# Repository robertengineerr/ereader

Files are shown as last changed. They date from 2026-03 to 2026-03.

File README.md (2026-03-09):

# e-reader

An open-source e-reader built on the ESP32-S3. Bare-metal C++ firmware, web-based book management, physical controls. Designed for FOSS developers to build on top of solid hardware.

## Schematic



The full KiCad project is in [`hardware/e_reader_v0.1/`](hardware/e_reader_v0.1/). Pin reference is in [`hardware/connections.md`](hardware/connections.md).

## Hardware

| Component | Part |
|---|---|
| MCU | ESP32-S3-DevKitC-1 (N16R8, 16MB flash, 8MB PSRAM) |
| Display | Waveshare 7.5" V2 e-ink (800×480) |
| Storage | MicroSD socket, SPI, FAT32 |
| Input | 7× tactile buttons |
| Battery | 3.7V LiPo via JST-PH, MCP73831 charger |
| Power | USB-C (charging + programming), AP2112 3.3V LDO |

### Wiring

**Display (FSPI / SPI2)**
| Signal | GPIO | Notes |
|---|---|---|
| PWR | 3 | Drive HIGH to power display |
| CS | 10 | |
| CLK | 9 | |
| DIN (MOSI) | 46 | |
| DC | 11 | |
| RST | 12 | |
| BUSY | 13 | |

**SD Card (HSPI / SPI3)**
| Signal | GPIO |
|---|---|
| CS | 15 |
| MOSI | 16 |
| SCK | 17 |
| MISO | 18 |

> Use a 3.3V-native SD socket (no onboard LDO). DAT1 and DAT2 must be pulled to 3.3V via 10k resistors.

**Buttons**
| Button | GPIO | Notes |
|---|---|---|
| UP | 36 | INPUT_PULLUP, FALLING interrupt |
| DOWN | 37 | INPUT_PULLUP, FALLING interrupt |
| LEFT | 38 | INPUT_PULLUP, FALLING interrupt |
| RIGHT | 39 | INPUT_PULLUP, FALLING interrupt |
| MID | 40 | INPUT_PULLUP, FALLING interrupt |
| SET | 41 | Hold at boot → WiFi mode |
| RST | 42 | Reserved |

## Building

1. Install [PlatformIO](https://platformio.org/)
2. Create `src/secrets.h` with your WiFi credentials:
```cpp
#define WIFI_SSID "your-ssid"
#define WIFI_PASS "your-password"
```
3. Build and flash:
```bash
pio run --target upload
```

## Usage

| Button | Library | Reading | Settings |
|---|---|---|---|
| UP | Cursor up | Previous page | Cursor up |
| DOWN | Cursor down | Next page | Cursor down |
| RIGHT | — | Next page | — |
| MID | Select | Back to library | Select |
| LEFT | — | Back to library | Back to library |
| Hold SET at boot | — | — | Enter WiFi mode |

### WiFi Upload

Hold SET while pressing reset, or navigate **Settings → WiFi Upload**. The device connects to your WiFi and shows `ereader.local` on screen. Open `http://ereader.local` in a browser to upload and delete books.

Supported formats (converted to plain text in the browser):
- `.txt` — uploaded directly
- `.epub` — extracted in browser via JSZip
- `.pdf` — extracted via PDF.js
- `.docx` — extracted via JSZip
- `.html` / `.htm` — stripped in browser
- `.fb2` — parsed in browser

Press MID on the device or click **Exit WiFi Mode** in the browser to return to the library.

### Fallback

If no SD card is present the device falls back to a built-in sample text (Iliad Book I, Pope translation) so the UI is always usable.

## Project Structure

```
src/
  main.cpp          # setup, loop, ISR input handling, state machine
  display.cpp/h     # e-ink display abstraction (GxEPD2)
  sd_manager.cpp/h  # SD card init, book listing, pagination engine
  network.cpp/h     # WiFi, HTTP file manager, mDNS
  web_ui.h          # embedded HTML/JS for the browser file manager
  secrets.h         # WiFi credentials (not in repo — create your own)

hardware/
  connections.md              # full pin reference for KiCad
  e_reader_v0.1/              # KiCad project (schematic + PCB)
```

## Roadmap

- [x] Text rendering on e-ink display
- [x] SD card file management
- [x] State machine UI (Library / Reading / Settings)
- [x] WiFi upload with multi-format support
- [x] mDNS (`ereader.local`)
- [x] Hardware schematic v0.1
- [ ] PCB layout and fabrication (JLCPCB)
- [ ] LiPo battery + charging circuit (MCP73831 + AP2112)
- [ ] Persist reading position (LittleFS)
- [ ] EPUB native rendering
- [ ] 3D printed enclosure

## License

MIT

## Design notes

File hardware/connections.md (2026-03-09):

# E-Reader v0.1 — Pin Connections Reference

KiCad project path: `/Users/robbiethomas/Documents/PlatformIO/Projects/e_reader_v0.1/hardware/`

MCU: **ESP32-S3-DevKitC-1 (N16R8)**

---

## E-Paper Display — Waveshare 7.5" V2 (800×480)
Interface: **FSPI (SPI2)**
Portrait orientation: 480px wide × 800px tall (setRotation(1))

| Display Pin | ESP32-S3 GPIO | Notes |
|---|---|---|
| PWR | GPIO3 | OUTPUT HIGH to power on |
| BUSY | GPIO13 | Input, active HIGH while refreshing |
| RST | GPIO12 | Active LOW reset |
| DC | GPIO11 | Data/Command select |
| CS | GPIO10 | SPI chip select, active LOW |
| CLK | GPIO9 | FSPI clock |
| DIN (MOSI)  | GPIO46 | FSPI MOSI |
| VCC | 3.3V | |
| GND | GND | |

SPI settings: 4 MHz, MSBFIRST, SPI_MODE0

---

## SD Card Module — UMLIFE 3.3V (or equivalent)
Interface: **HSPI (SPI3)**

| SD Pin | ESP32-S3 GPIO | Notes |
|---|---|---|
| CS | GPIO15 | SPI chip select, active LOW |
| MOSI | GPIO16 | HSPI MOSI |
| SCK | GPIO17 | HSPI clock |
| MISO | GPIO18 | HSPI MISO |
| VCC | 3.3V | Must be 3.3V-native module (no onboard LDO) |
| GND | GND | |

SPI speed: 4 MHz. FAT32 formatted, .txt files in root.

---

## 5-Way Joystick
COM pin is driven LOW by GPIO (virtual GND). All direction pins are INPUT_PULLUP — pressed = LOW (FALLING edge interrupt).

| Joystick Pin | ESP32-S3 GPIO | Mode | Function |
|---|---|---|---|
| COM | GPIO35 | OUTPUT LOW | Virtual GND for joystick |
| UP | GPIO36 | INPUT_PULLUP + INT | Navigate up / previous page |
| DOWN | GPIO37 | INPUT_PULLUP + INT | Navigate down / next page |
| LEFT | GPIO38 | INPUT_PULLUP + INT | Back to library |
| RIGHT | GPIO39 | INPUT_PULLUP + INT | Next page (reading mode) |
| MID (press)  | GPIO40 | INPUT_PULLUP + INT | Select / back to library / exit WiFi |
| SET | GPIO41 | INPUT_PULLUP | Hold at boot → enter WiFi upload mode |
| RST | GPIO42 | INPUT_PULLUP | Reserved (reset / future use) |

All interrupts: FALLING edge, ISR-side debounce at 200 ms.

---

## Power Rails
| Rail  | Source | Consumers |
|---|---|---|
| 3.3V  | DevKitC onboard reg / LiPo + regulator (future) | Display VCC, SD VCC, joystick pull-ups |
| GND | Common ground | All components |

---

## Unused / Reserved GPIOs (available for future use)
GPIO0, GPIO1, GPIO2, GPIO4, GPIO5, GPIO6, GPIO7, GPIO8, GPIO14, GPIO19–GPIO21, GPIO43–GPIO45, GPIO47, GPIO48

---

## WiFi
No external antenna wiring — onboard PCB antenna on DevKitC-1.
SSID / password stored in `src/secrets.h` (not committed to git).
mDNS hostname: `ereader.local`

---

## Notes for Schematic
- Add 100 nF decoupling caps on all VCC pins close to each IC
- Pull-up resistors on BUSY, RST are handled internally by GxEPD2 / MCU
- SD MISO should have a 10k pull-up to 3.3V (some modules include this)
- GPIO35 (JOY_COM) must be rated OUTPUT; on ESP32-S3-DevKitC-1 this is fine
- Future: LiPo charger (TP4056), 3.3V LDO (AP2112K or similar), power switch

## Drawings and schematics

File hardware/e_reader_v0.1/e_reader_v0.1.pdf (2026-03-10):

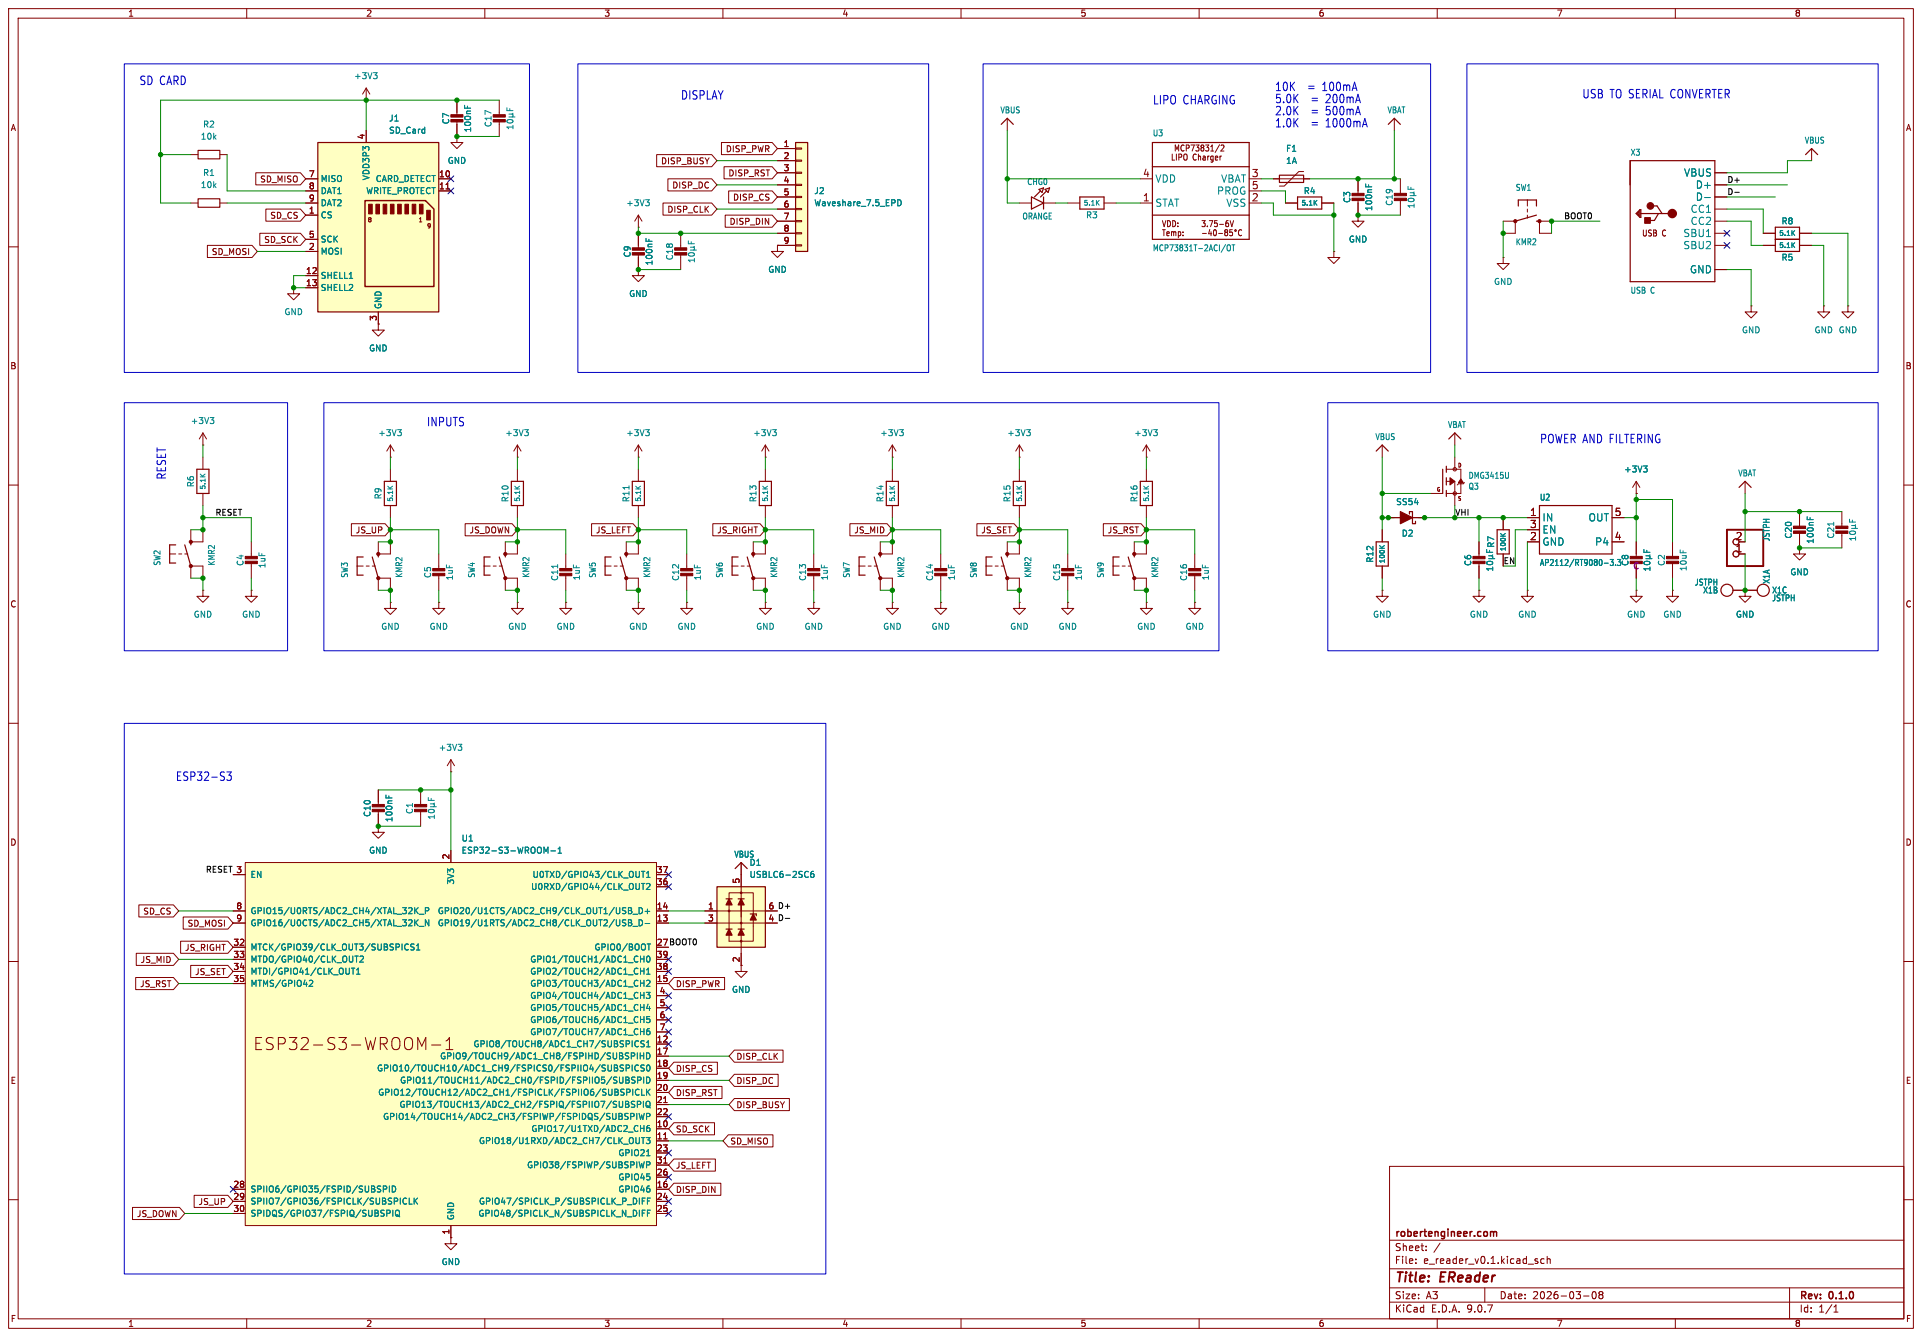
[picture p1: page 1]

USB TO SERIAL CONVERTER

VDD: Temp: LIPO Charger MCP73831/2

1 U0TXD/GPIO43/CLK_OUT1 37 U0RXD/GPIO44/CLK_OUT2 36 GPIO20/U1CTS/ADC2_CH9/CLK_OUT1/USB_D+ 14 GPIO19/U1RTS/ADC2_CH8/CLK_OUT2/USB_D- 13 GPIO0/BOOT 27 GPIO1/TOUCH1/ADC1_CH0 39 GPIO2/TOUCH2/ADC1_CH1 38 GPIO3/TOUCH3/ADC1_CH2 15 GPIO4/TOUCH4/ADC1_CH3 4 GPIO5/TOUCH5/ADC1_CH4 5 GPIO6/TOUCH6/ADC1_CH5 6 GPIO7/TOUCH7/ADC1_CH6 7 GPIO8/TOUCH8/ADC1_CH7/SUBSPICS1 12 GPIO9/TOUCH9/ADC1_CH8/FSPIHD/SUBSPIHD 17 GPIO10/TOUCH10/ADC1_CH9/FSPICS0/FSPIIO4/SUBSPICS0 18 GPIO11/TOUCH11/ADC2_CH0/FSPID/FSPIIO5/SUBSPID 19 GPIO12/TOUCH12/ADC2_CH1/FSPICLK/FSPIIO6/SUBSPICLK 20 GPIO13/TOUCH13/ADC2_CH2/FSPIQ/FSPIIO7/SUBSPIQ 21 GPIO14/TOUCH14/ADC2_CH3/FSPIWP/FSPIDQS/SUBSPIWP 22 GPIO17/U1TXD/ADC2_CH6 10 GPIO18/U1RXD/ADC2_CH7/CLK_OUT3 11 GPIO21 23 GPIO38/FSPIWP/SUBSPIWP 31 GPIO45 26 GPIO46 16 GPIO47/SPICLK_P/SUBSPICLK_P_DIFF 24 GPIO48/SPICLK_N/SUBSPICLK_N_DIFF 25 U1ESP32-S3-WROOM-1 GND C15 1uF

1 U0TXD/GPIO43/CLK_OUT1 37 U0RXD/GPIO44/CLK_OUT2 36 GPIO20/U1CTS/ADC2_CH9/CLK_OUT1/USB_D+ 14 GPIO19/U1RTS/ADC2_CH8/CLK_OUT2/USB_D- 13 GPIO0/BOOT 27 GPIO1/TOUCH1/ADC1_CH0 39 GPIO2/TOUCH2/ADC1_CH1 38 GPIO3/TOUCH3/ADC1_CH2 15 GPIO4/TOUCH4/ADC1_CH3 4 GPIO5/TOUCH5/ADC1_CH4 5 GPIO6/TOUCH6/ADC1_CH5 6 GPIO7/TOUCH7/ADC1_CH6 7 GPIO8/TOUCH8/ADC1_CH7/SUBSPICS1 12 GPIO9/TOUCH9/ADC1_CH8/FSPIHD/SUBSPIHD 17 GPIO10/TOUCH10/ADC1_CH9/FSPICS0/FSPIIO4/SUBSPICS0 18 GPIO11/TOUCH11/ADC2_CH0/FSPID/FSPIIO5/SUBSPID 19 GPIO12/TOUCH12/ADC2_CH1/FSPICLK/FSPIIO6/SUBSPICLK 20 GPIO13/TOUCH13/ADC2_CH2/FSPIQ/FSPIIO7/SUBSPIQ 21 GPIO14/TOUCH14/ADC2_CH3/FSPIWP/FSPIDQS/SUBSPIWP 22 GPIO17/U1TXD/ADC2_CH6 10 GPIO18/U1RXD/ADC2_CH7/CLK_OUT3 11 GPIO21 23 GPIO38/FSPIWP/SUBSPIWP 31 GPIO45 26 GPIO46 16 GPIO47/SPICLK_P/SUBSPICLK_P_DIFF 24 GPIO48/SPICLK_N/SUBSPICLK_N_DIFF 25 GND C10 100nF D1 USBLC6-2SC6

Id: 1/1 Title: EReader File: e_reader_v0.1.kicad_sch Sheet: / robertengineer.com

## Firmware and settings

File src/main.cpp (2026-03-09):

#include <Arduino.h>
#include "display.h"
#include "sd_manager.h"
#include "network.h"

// --- 5-way joystick ---
// COM is wired to a GPIO configured OUTPUT LOW (virtual GND)
#define JOY_COM  35
#define JOY_UP   36
#define JOY_DWN  37
#define JOY_LFT  38
#define JOY_RHT  39
#define JOY_MID  40
#define JOY_SET  41  // hold at boot to enter WiFi upload mode
#define JOY_RST  42

#define DEBOUNCE_MS 200

// Flags set by ISRs; read and cleared in loop()
static volatile bool ev_up    = false;
static volatile bool ev_down  = false;
static volatile bool ev_left  = false;
static volatile bool ev_right = false;
static volatile bool ev_mid   = false;

// Per-button last-fire timestamp for ISR-side debounce
static volatile uint32_t t_up    = 0;
static volatile uint32_t t_down  = 0;
static volatile uint32_t t_left  = 0;
static volatile uint32_t t_right = 0;
static volatile uint32_t t_mid   = 0;

static void IRAM_ATTR isr_up()    { uint32_t n=millis(); if(n-t_up   >DEBOUNCE_MS){ev_up   =true;t_up   =n;} }
static void IRAM_ATTR isr_down()  { uint32_t n=millis(); if(n-t_down >DEBOUNCE_MS){ev_down =true;t_down =n;} }
static void IRAM_ATTR isr_left()  { uint32_t n=millis(); if(n-t_left >DEBOUNCE_MS){ev_left =true;t_left =n;} }
static void IRAM_ATTR isr_right() { uint32_t n=millis(); if(n-t_right>DEBOUNCE_MS){ev_right=true;t_right=n;} }
static void IRAM_ATTR isr_mid()   { uint32_t n=millis(); if(n-t_mid  >DEBOUNCE_MS){ev_mid  =true;t_mid  =n;} }

// --- App state ---
enum AppState { LIBRARY, READING, SETTINGS };

static AppState appState     = LIBRARY;
static int      selectedItem = 0;   // cursor position in LIBRARY or SETTINGS
static int      listScroll   = 0;   // scroll offset for LIBRARY list
static int      currentPage  = 0;

static char bookNames[MAX_BOOKS][MAX_NAME_LEN];
static int  bookCount = 0;

static const char* settingsItems[] = { "WiFi Upload", "Back" };
static const int   SETTINGS_COUNT  = 2;

// ---------------------------------------------------------------------------
// Helpers
// ---------------------------------------------------------------------------

static void clampScroll(int selected, int& scroll, int visible, int total) {
  if (selected < scroll)            scroll = selected;
  if (selected >= scroll + visible) scroll = selected - visible + 1;
}

static void enterLibrary();  // forward declaration

static void returnToLibrary() {
  showPressAnyButton();
  ev_up = ev_down = ev_left = ev_right = ev_mid = false;  // clear stale presses
  while (!ev_up && !ev_down && !ev_left && !ev_right && !ev_mid) delay(10);
  ev_up = ev_down = ev_left = ev_right = ev_mid = false;
  enterLibrary();
}

static void enterLibrary() {
  bookCount = listBooks(bookNames, MAX_BOOKS - 1);
  if (bookCount == 0) {
    strncpy(bookNames[0], "Sample: The Iliad", MAX_NAME_LEN - 1);
    bookNames[0][MAX_NAME_LEN - 1] = '\0';
    bookCount = 1;
  }
  selectedItem = 0;
  listScroll   = 0;
  appState     = LIBRARY;
  showLibraryScreen(bookNames, bookCount, selectedItem, listScroll);
}

// ---------------------------------------------------------------------------
// Setup
// ---------------------------------------------------------------------------

void setup() {
  Serial.begin(115200);

  // Joystick: COM acts as virtual GND so direction pins read LOW when pressed
  pinMode(JOY_COM, OUTPUT);
  digitalWrite(JOY_COM, LOW);
  pinMode(JOY_UP,  INPUT_PULLUP);
  pinMode(JOY_DWN, INPUT_PULLUP);
  pinMode(JOY_LFT, INPUT_PULLUP);
  pinMode(JOY_RHT, INPUT_PULLUP);
  pinMode(JOY_MID, INPUT_PULLUP);
  pinMode(JOY_SET, INPUT_PULLUP);
  pinMode(JOY_RST, INPUT_PULLUP);

  attachInterrupt(JOY_UP,  isr_up,    FALLING);
  attachInterrupt(JOY_DWN, isr_down,  FALLING);
  attachInterrupt(JOY_LFT, isr_left,  FALLING);
  attachInterrupt(JOY_RHT, isr_right, FALLING);
  attachInterrupt(JOY_MID, isr_mid,   FALLING);

  initSD();
  initDisplay();

  // Hold SET at boot → WiFi upload mode
  if (digitalRead(JOY_SET) == LOW) {
    runWifiMode();
    returnToLibrary();
    return;
  }

  showBootScreen();
  delay(1000);
  enterLibrary();
}

// ---------------------------------------------------------------------------
// Loop — state machine
// ---------------------------------------------------------------------------

void loop() {
  if (!ev_up && !ev_down && !ev_left && !ev_right && !ev_mid) return;

  // Snapshot and clear flags atomically
  bool up    = ev_up;    ev_up    = false;
  bool down  = ev_down;  ev_down  = false;
  bool left  = ev_left;  ev_left  = false;
  bool right = ev_right; ev_right = false;
  bool mid   = ev_mid;   ev_mid   = false;

  int totalItems;

  switch (appState) {

    // ---- Library ----
    case LIBRARY:
      totalItems = bookCount + 1;  // books + "Settings"
      if (up && selectedItem > 0) {
        selectedItem--;
        clampScroll(selectedItem, listScroll, LIBRARY_VISIBLE, totalItems);
        showLibraryScreen(bookNames, bookCount, selectedItem, listScroll);
      } else if (down && selectedItem < totalItems - 1) {
        selectedItem++;
        clampScroll(selectedItem, listScroll, LIBRARY_VISIBLE, totalItems);
        showLibraryScreen(bookNames, bookCount, selectedItem, listScroll);
      } else if (mid) {
        if (selectedItem < bookCount) {
          openBook(bookNames[selectedItem]);  // failure falls back to sample text
          scanPages();
          currentPage = 0;
          appState    = READING;
          showPage(currentPage);
        } else {
          selectedItem = 0;
          listScroll   = 0;
          appState     = SETTINGS;
          showSettingsScreen(settingsItems, SETTINGS_COUNT, selectedItem);
        }
      }
      break;

    // ---- Reading ----
    case READING:
      if ((down || right) && currentPage < totalPages - 1) {
        currentPage++;
        showPage(currentPage);
      } else if (up && currentPage > 0) {
        currentPage--;
        showPage(currentPage);
      } else if (left || mid) {
        enterLibrary();
      }
      break;

    // ---- Settings ----
    case SETTINGS:
      if (up && selectedItem > 0) {
        selectedItem--;
        showSettingsScreen(settingsItems, SETTINGS_COUNT, selectedItem);
      } else if (down && selectedItem < SETTINGS_COUNT - 1) {
        selectedItem++;
        showSettingsScreen(settingsItems, SETTINGS_COUNT, selectedItem);
      } else if (mid) {
        if (selectedItem == 0) {
          runWifiMode();
          returnToLibrary();
        } else {
          enterLibrary();
        }
      } else if (left) {
        enterLibrary();
      }
      break;
  }
}

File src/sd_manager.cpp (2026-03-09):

#include <Arduino.h>
#include <SPI.h>
#include <SD.h>
#include "sd_manager.h"
#include "display.h"   // for CHARS_PER_LINE, LINES_PER_PAGE

// --- SD card pins (HSPI / SPI3) ---
#define SD_CS    15
#define SD_MOSI  16
#define SD_SCK   17
#define SD_MISO  18

static SPIClass sdSPI(HSPI);
static bool sdMounted = false;
static bool usingSD   = false;
static File bookFile;

// Built-in sample — The Iliad, Book I (Alexander Pope translation, 1899, public domain)
static const char* fallbackText =
  "THE ILIAD OF HOMER - BOOK I\n"
  "Translated by Alexander Pope\n\n"
  "Achilles' wrath, to Greece the direful spring\n"
  "Of woes unnumber'd, heavenly goddess, sing!\n"
  "That wrath which hurl'd to Pluto's gloomy reign\n"
  "The souls of mighty chiefs untimely slain;\n"
  "Whose limbs unburied on the naked shore,\n"
  "Devouring dogs and hungry vultures tore.\n"
  "Since great Achilles and Atrides strove,\n"
  "Such was the sovereign doom, and such the will of Jove!\n"
  "Declare, O Muse! in what ill-fated hour\n"
  "Sprung the fierce strife, from what offended power\n"
  "Latona's son a dire contagion spread,\n"
  "And heap'd the camp with mountains of the dead;\n"
  "The king of men his reverent priest defied,\n"
  "And for the king's offence the people died.\n\n"
  "For Chryses sought with costly gifts to gain\n"
  "His captive daughter from the victor's chain.\n"
  "Suppliant the venerable father stands;\n"
  "Apollo's awful ensigns grace his hands:\n"
  "By these he begs; and lowly bending down,\n"
  "Extends the sceptre and the laurel crown.\n"
  "He sued to all, but chief implored for grace\n"
  "The brother-kings, of Atreus' royal race:\n"
  "\"Ye kings and warriors! may your vows be crown'd,\n"
  "And Troy's proud walls lie level with the ground.\n"
  "May Jove restore you when your toils are o'er\n"
  "Safe to the pleasures of your native shore.\n"
  "But, oh! relieve a wretched parent's pain,\n"
  "And give Chryseis to these arms again;\n"
  "If mercy fail, yet let my presents move,\n"
  "And dread avenging Phoebus, son of Jove.\"\n\n"
  "The Greeks in shouts their joint assent declare,\n"
  "The priest to reverence, and release the fair.\n"
  "Not so Atrides; he, with kingly pride,\n"
  "Repulsed the sacred sire, and thus replied:\n"
  "\"Hence on thy life, and fly these hostile plains,\n"
  "Nor ask, presumptuous, what the king detains:\n"
  "Hence, with thy laurel crown, and golden rod,\n"
  "Nor trust too far those ensigns of thy god.\n"
  "Mine is thy daughter, priest, and shall remain;\n"
  "And prayers, and tears, and bribes, shall plead in vain;\n"
  "Till time shall rifle every youthful grace,\n"
  "And age dismiss her from my cold embrace,\n"
  "In daily labours of the loom employ'd,\n"
  "Or doom'd to deck the bed she once enjoy'd.\n"
  "Hence then; to Argos shall the maid retire,\n"
  "Far from her native soil and weeping sire.\"\n\n"
  "The trembling priest along the shore return'd,\n"
  "And in the anguish of a father mourn'd.\n"
  "Disconsolate, not daring to complain,\n"
  "Silent he wander'd by the sounding main;\n"
  "Till, safe at distance, to his god he prays,\n"
  "The god who darts around the world his rays:\n"
  "\"O Smintheus! sprung from fair Latona's line,\n"
  "Thou guardian power of Cilla the divine,\n"
  "Thou source of light! whom Tenedos adores,\n"
  "And whose bright presence gilds thy Chrysa's shores.\n"
  "If e'er with wreaths I hung thy sacred fane,\n"
  "Or fed the flames with fat of oxen slain;\n"
  "God of the silver bow! thy shafts employ,\n"
  "Avenge thy servant, and the Greeks destroy.\"\n\n"
  "Thus Chryses pray'd: the favouring power attends,\n"
  "And from Olympus' lofty tops descends.\n"
  "Bent was his bow, the Grecian hearts to wound;\n"
  "Fierce as he moved, his silver shafts resound.\n"
  "Breathing revenge, a sudden night he spread,\n"
  "And gloomy darkness roll'd about his head.\n"
  "The fleet in view, he twang'd his deadly bow,\n"
  "And hissing fly the feather'd fates below.\n"
  "On mules and dogs the infection first began;\n"
  "And last, the vengeful arrows fix'd in man.\n"
  "For nine long nights, through all the dusky air,\n"
  "The pyres, thick-flaming, shot a dismal glare.";

int totalPages = 0;
static uint32_t pageOffsets[MAX_PAGES];

bool initSD() {
  delay(100);  // let card power stabilise
  sdSPI.begin(SD_SCK, SD_MISO, SD_MOSI, -1);
  if (!SD.begin(SD_CS, sdSPI, 4000000)) {
    Serial.println("=== SD FAILED — check wiring and FAT32 format ===");
    sdMounted = false;
    return false;
  }
  uint8_t t = SD.cardType();
  Serial.printf("=== SD OK: %s, %llu MB ===\n",
    t==CARD_MMC?"MMC": t==CARD_SD?"SD": t==CARD_SDHC?"SDHC":"?",
    SD.cardSize() / (1024ULL * 1024));
  sdMounted = true;
  return true;
}

int listBooks(char names[][MAX_NAME_LEN], int maxBooks) {
  if (!sdMounted) return 0;
  int count = 0;
  File root = SD.open("/");
  if (!root) return 0;
  File f = root.openNextFile();
  while (f && count < maxBooks) {
    String name  = f.name();
    bool   isDir = f.isDirectory();
    f.close();
    if (!isDir) {
      String lower = name;
      lower.toLowerCase();
      if (lower.endsWith(".txt")) {
        strncpy(names[count], name.c_str(), MAX_NAME_LEN - 1);
        names[count][MAX_NAME_LEN - 1] = '\0';
        count++;
      }
    }
    f = root.openNextFile();
  }
  root.close();
  return count;
}

bool openBook(const char* filename) {
  if (bookFile) bookFile.close();
  String path = (filename[0] == '/') ? String(filename) : "/" + String(filename);
  bookFile = SD.open(path);
  if (!bookFile) {
    Serial.printf("Failed to open %s\n", path.c_str());
    usingSD = false;
    return false;
  }
  usingSD = true;
  Serial.printf("Opened %s\n", path.c_str());
  return true;
}

void scanPages() {
  int charsPerPage = CHARS_PER_LINE * LINES_PER_PAGE;
  totalPages = 0;

  if (usingSD) {
    bookFile.seek(0);
    pageOffsets[totalPages++] = 0;
    uint32_t charCount = 0;
    while (bookFile.available() && totalPages < MAX_PAGES) {
      bookFile.read();
      charCount++;
      if (charCount % charsPerPage == 0)
        pageOffsets[totalPages++] = bookFile.position();
    }
  } else {
    int textLen = strlen(fallbackText);
    pageOffsets[totalPages++] = 0;
    for (int i = charsPerPage; i < textLen && totalPages < MAX_PAGES; i += charsPerPage)
      pageOffsets[totalPages++] = i;
  }

  Serial.printf("Scanned %d pages\n", totalPages);
}

int getLine(int pageNum, int lineNum, char* buf, int maxLen) {
  int len = 0;
  uint32_t offset = pageOffsets[pageNum] + ((uint32_t)lineNum * maxLen);

  if (usingSD) {
    bookFile.seek(offset);
    while (len < maxLen && bookFile.available())
      buf[len++] = (char)bookFile.read();
  } else {
    int textLen = strlen(fallbackText);
    while (len < maxLen && (offset + len) < (uint32_t)textLen) {
      buf[len] = fallbackText[offset + len];
      len++;
    }
  }

  buf[len] = '\0';
  return len;
}

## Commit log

2026-03-06 Initial commit: ESP32-S3 e-reader firmware
    State machine UI (library/reading/settings), SD card management,
    WiFi book upload, interrupt-driven joystick input, GxEPD2 e-ink display.
2026-03-09 Add hardware schematic reference and update firmware
    - ISR-based input handling, state machine UI (Library/Reading/Settings)
    - 7.5" 800x480 display support, portrait orientation
    - SD card manager with sdMounted guard and MAX_NAME_LEN=128 fix
    - WiFi upload mode with mDNS, multi-format browser conversion, exit endpoint
    - hardware/connections.md: comprehensive pin reference for KiCad schematic
    [e_reader_v0.1.kicad_pcb, e_reader_v0.1.kicad_sch, freerouting.dsn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]
2026-03-09 Update .gitignore for KiCad temp files and book files
2026-03-09 Update README with correct hardware, KiCanvas schematic link, full docs
2026-03-09 Add schematic v0.1 with power, display, SD, buttons, USB-C, LiPo charging
    [Adafruit ESP32-S3 8MB No PSRAM.kicad_sch, Adafruit ESP32-S3 8MB No PSRAM.sch, e_reader_v0.1.kicad_sch]
2026-03-09 Update README: buttons, battery management, schematic status
2026-03-09 Switch U1 to ESP32-S3-WROOM-1, update schematic components
    - Replace ESP32-S3-DevKitC with WROOM-1 module symbol
    - Swap D4 MBR540 (through-hole) for SS54 (SMA SMD)
    - Fix USBLC6 VP pin: connect to VBUS instead of +3V3
    - Assign correct footprints to U3 MCP73831, D1 USBLC6
    [e_reader_v0.1.kicad_sch]
2026-03-10 Fix footprints, add power switch and battery voltage divider
    - Fix SW1-SW9 KMR2 footprints (were incorrectly set to USB-C)
    - Add SW10 power switch (Nidec CAS-120A1)
    - Add R17/R18 battery voltage divider (110K) for ADC battery monitoring
    - Assign correct SOT-23-5 footprints to U2, U3
    - Fix D2 SS54, D1 USBLC6, Q3 DMG3415U footprints
    [e_reader_v0.1.kicad_sch]
2026-11-05 Schematic rev 0.2.0: fix power switch, pin/pad mismatches, add 5-way joystick
    Electrical fixes
    - Power switch SW10 now drives the 3V3 regulator EN (was only gating the
    charger); charger VDD fed straight from VBUS with 4.7uF input cap (C22)
    - microSD: full-size SD symbol on a microSD footprint scrambled the pinout;
    now Micro_SD_Card_Det2 + Molex 104031-0811, card-detect on GPIO6
    - JS_UP/JS_DOWN moved off GPIO36/37 (octal PSRAM on N16R8) to GPIO4/5
    - DISP_DIN moved off strapping pin GPIO46 to GPIO14
    - Battery divider 5.1K/5.1K (~410uA drain) -> 100K/100K + 100nF (C23)
    - 10K pull-ups on SD_MISO/SD_CS, RESET pull-up 5.1K -> 10K
    - PWR_FLAGs, no-connect on U2 pin 4, removed stray wire stubs
    S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
2026-11-05 Update connections.md for breadboard and PCB pin maps
    Claude-Session: https://claude.ai/code/session_01Suq4ptutFEVn8uhZfn8avC
2026-11-05 Schematic review round 1 fixes: battery protection, low-Iq LDO, TVS
    From review round 1 (scores 7/8/6):
    - F1 moved from the charger output to the battery input so it protects
    the whole board; added Q4 DMG3415U reverse-polarity P-FET
    - U2 AP2112K -> RT9080-33GJ5 (same pinout, ~2uA vs ~55uA Iq)
    - Battery divider 100K/100K -> 470K/470K (less drain and GPIO back-feed)
    - R3 charge-LED resistor 5.1K -> 2.2K so the LED is visible
    - SMAJ5.0A TVS (D3) on VBUS; joystick mounting pads to GND
    - BOM: LCSC/MPN for new parts, hand-solder notes for J2/SW10, unit cleanup
    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
2026-11-05 Schematic review round 2 fixes: SD pull-ups, PCB build env
    From review round 2 (scores 8/4/8). The 4 came from a misread of SW10's
    common pin; the KiCad symbol (SW_SPDT_321) has pin 2 as common, so the
    wiring is correct. Added a note on the sheet to make that clear.
    - R21 10K pull-up on SD CMD, R22 10K pull-up on SD card-detect
    - SD pull-ups consolidated in one column; J1 moved down for clarity
    - platformio [env:pcb]: USB-CDC on boot (no UART bridge on the board),
    16 MB flash, qio_opi memory type and PSRAM for the N16R8 module
    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
2026-11-05 Latch SET-held-at-boot before SD/display init
    The WiFi-mode check ran after initSD()/initDisplay(), so the button had to
    be held for several seconds. Read it right after pin setup instead.
    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
2026-11-05 Schematic review round 3 fixes, regenerated PDF/BOM, review log
    From review round 3 (scores 8/8/6):
    - R12 100K -> 10K so VBUS bleeds quickly and Q3 takes over on unplug
    - R7 1M pull-down on regulator EN (no float during switch travel)
    - TP1-TP6 bring-up pads: VBAT, VHI, 3V3, GND, UART0 TX/RX (GPIO43/44)
    - Battery connector polarity note; tidied INPUTS footnote
    Also regenerates e_reader_v0.1.pdf (it was stale), exports a BOM with
    verified LCSC numbers, adds hardware/REVIEW.md (scores, accepted and
    rejected findings, pre-order checklist) and updates README/connections.md.
    Claude-Session: https://claude.ai/code/session_01Suq4ptutFEVn8uhZ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
2026-11-05 All-SMD BOM: SMD power switch and display header for full JLCPCB assembly
    - SW10: Nidec CAS-120A1 (not at LCSC) -> C&K PCM12SMTR (LCSC C221841) on
    KiCad's SW_SPDT_PCM12 footprint; pads checked against LCSC land pattern,
    same SW_SPDT_321 pinout (pin 2 common), wiring unchanged
    - J2: THT 1x09 header -> SMD 1x09 2.54mm male header INCP IPCP254M09PB08S
    (LCSC C22438433) with a footprint built from the LCSC land pattern
    - Every BOM line now has an LCSC part number; no hand soldering needed
    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
2026-11-05 PCB: 4-layer 68x50mm board with all parts placed (not yet routed)
    Generated from the schematic netlist with hardware/tools/gen_pcb.py:
    - ESP32-S3 antenna on the top edge with the module's keep-out, display
    header top-right, joystick + SET/RST on the right edge, USB-C, power
    slider and battery JST on the bottom edge, microSD slot on the left
    - In1 = GND plane, In2 = +3V3 plane; JLCPCB-safe rules (0.15/0.15mm,
    0.3mm vias, 0.2mm min drill), Power net class 0.4mm
    - 3x M2.5 mounting holes; every passive next to the pin it serves
    - DRC: 0 schematic-parity errors, 0 courtyard/clearance violations;
    180 unconnected pads remain because routing has not been done yet
    - e_reader_v0.1.dsn exported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
2026-11-05 Add grid router for the PCB (pcbnew + numpy, A* with vias, plane stubs)
    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
2026-11-05 Router: clearance margins for grid discretisation, hole rules, solid GND pours
    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
2026-11-05 PCB tools: power net class 0.3mm/0.15mm so VBUS can escape USB-C pins
    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
2026-11-05 PCB: real net classes/rules in project; router early fan-out for USB-C/microSD
    - e_reader_v0.1.kicad_pro: Default 0.15mm clearance / 0.2mm track, Power class
    0.3mm with patterns, 0.3mm edge clearance, 0.2mm min drill (JLCPCB 4-layer)
    - router: route USB-C and microSD nets first as rippable nets, then plane stubs;
    pads with no via room join their net's nearest copper instead
    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
2026-11-05 PCB: fully routed 4-layer board + JLCPCB fabrication files
    - All nets routed with hardware/tools/route_pcb.py (grid A*, rip-up and
    reroute, plane stubs to In1 GND / In2 +3V3, GND pours on F/B.Cu)
    - KiCad DRC with schematic parity: 0 unconnected pads, 0 clearance/hole/
    edge errors, 0 footprint mismatches; 17 silkscreen-only warnings
    - fab/: Gerbers + Excellon drill (zipped for upload), JLCPCB BOM with LCSC
    numbers for all 65 assembled parts, and the CPL placement file
    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
2026-11-05 PCB: layout review fixes - ESP32 decoupling, USB ESD placement, fiducials
    From the layout review round (electrical 7/10, DFM 7/10):
    - ESP32 moved 3.5 mm so C10/C1 sit 2.6/4.9 mm from the 3V3 pin (were ~20 mm)
    - D1 USB ESD 2.8 mm from the USB-C data pads; battery input caps next to X1
    - 3 fiducials for SMT assembly; board revision 0.2.0 in title block/Gerbers
    - router keeps tracks out of fiducial clearance + mask opening
    DRC with schematic parity: 0 unconnected, 0 electrical errors, 17 silk-only
    warnings. Regenerated Gerbers/drill zip and CPL; REVIEW.md has the ordering
    checklist (verify part rotations in JLCPCB's placement preview).
    C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
2026-11-05 Firmware/docs fixes from the 10-reviewer evaluation
    - platformio.ini: default_envs = breadboard, so `pio run` no longer builds
    and uploads both targets
    - network.cpp: use JOY_MID from pins.h instead of hard-coded GPIO40
    - connections.md/README: first-flash procedure for the PCB (SW10 ON, hold
    BOOT, tap RESET); mark card-detect and battery sense as hardware-only
    - router: no vias along the ESP32 antenna-side rim
    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
2026-11-05 PCB: fixes from the 10-reviewer evaluation (microSD slot orientation)
    - J1 microSD rotated +90 deg: the card mouth is on the signal-pad side,
    so the old placement had the slot facing into the board (mechanical
    reviewer, critical). Card now inserts from the left edge.
    - D3 VBUS TVS next to the USB-C VBUS pins; no vias at the antenna rim
    - Re-routed (0 unconnected, 0 electrical DRC errors), Gerbers/CPL
    regenerated, REVIEW.md records all 10 scores and what was fixed or
    rejected
    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
2026-11-05 fab: list every designator in the JLCPCB BOM (JLCPCB does not expand ranges like C11-C16)
    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
2026-11-05 fab: CPL with computed JLCPCB placement corrections
    hardware/tools/jlc_cpl_fix.py fits each part's JLCPCB/EasyEDA footprint
    (from the LCSC part data) onto the KiCad board pads and writes the
    placement JLCPCB needs:
    - U1 ESP32 centroid offset 3.56 mm, X3 USB-C offset 1.57 mm
    - J1 microSD rotated 180 deg relative to KiCad
    - SOT-23 (Q3/Q4) +180, SOT-23-5/6 (U2/U3/D1) +270
    - LED and SS54 pad numbering differs (JLC pad 1 = anode); mapped by pin
    name so polarity is kept
    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
